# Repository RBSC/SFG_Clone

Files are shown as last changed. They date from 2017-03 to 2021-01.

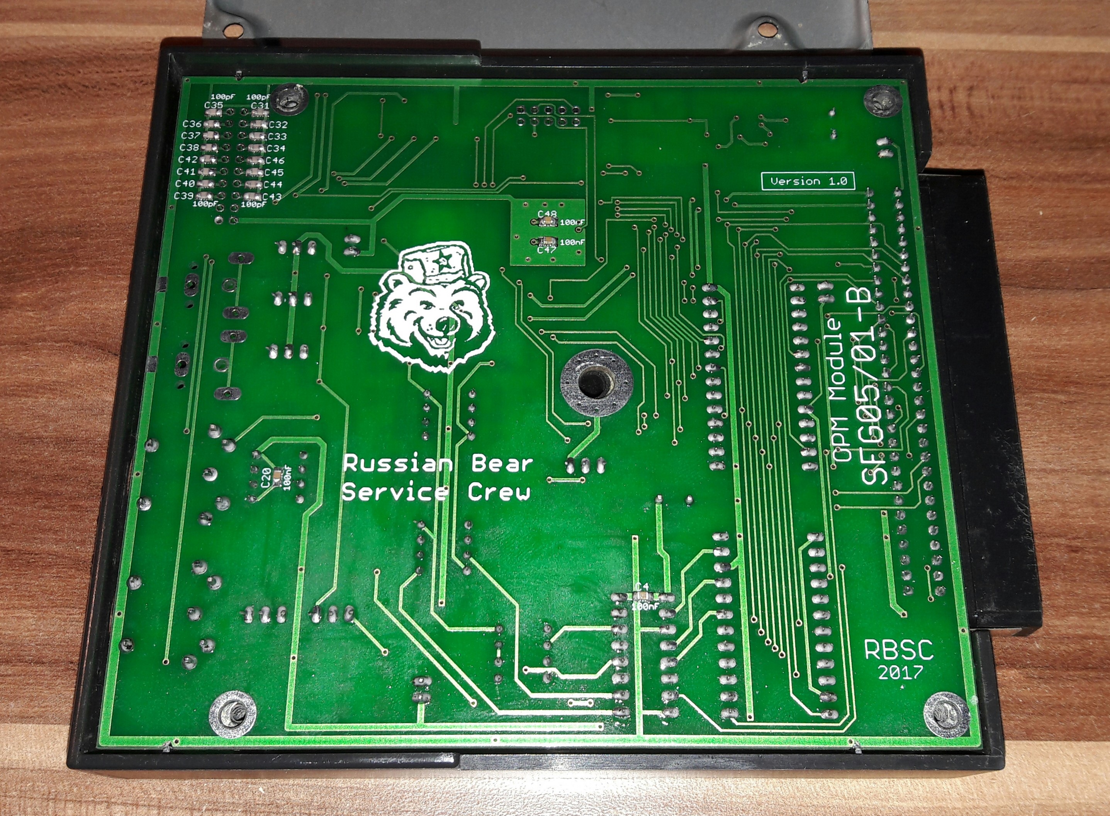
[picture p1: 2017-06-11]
Pics/assembled_clone_back.jpg

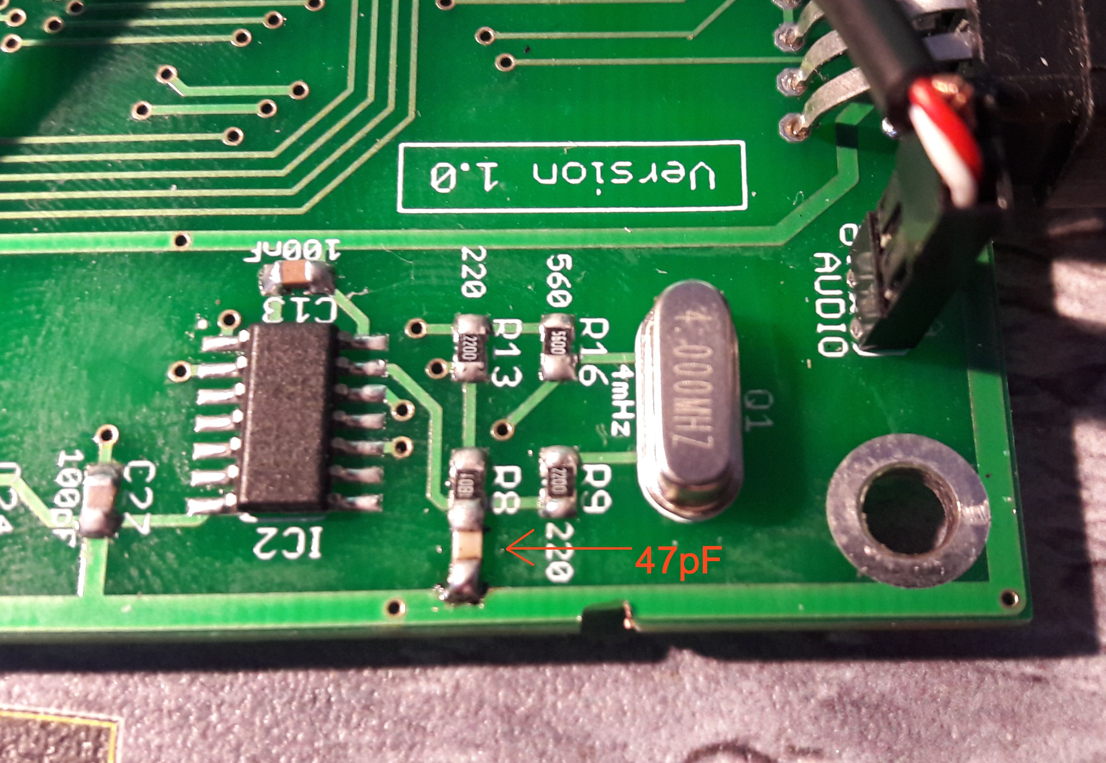
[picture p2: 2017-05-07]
Pics/74HCT04_fix.jpg

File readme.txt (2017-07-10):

Yamaha SFG 05/01-B Clone Board v1.1
Copyright (c) 2017 RBSC

The Setup
---------

After assembling, the board needs to be programmed in order to function properly. The following steps are necessary:

 1. Upload the Altera's firmware
 2. Program the BIOS with the provided ROM file

How to upload the firmware
--------------------------

The below instructions are for programming the Altera chip.

 1. Solder jumper pins to the "+5v" and "GND" soldering points on the board
 2. Prepare the ByteBlaster 2 programmer, open the Quartus II software, keep default JTAG selection
 3. Supply 5v power to the board via jumper pins (mind the correct polarity!)
 4. Connect the ByteBlaster's cable to the AS socket of the board (make sure you connect the cable correctly!)
 5. Click "Autodetect" in Quartus II software, the Altera chip should be found and ready for programming
 6. Use "Change file" option and select the .POF file from the "Firmware" directory
 7. Enable the checkboxes: "Program/Configure", "Verify" and "Blank Check"
 8. Click "Start" and monitor the programming and verification process

If the programming completed successfully, disconnect the ByteBlaster's cable and 5v power from the board.

You must also write the provided ROM file from BIOS directory into the 27C512 EPROM/EEPROM chip (DIP28) using any EEPROM
programmer. The ROM file contains 2 different BIOS versions that can be selected by the special jumper on the board. It is
also possible to use 27C256 EPROM/EEPROM chip to only have one of the BIOS versions instead of two.

Installing the audio wire
-------------------------

In order to connect the audio from the SFG board to MSX's internal amplifier a shielded wire must be installed between soldering
points named "X8A" and "X8B". The easiest way is to solder two 2-pin jumper pins onto those soldering points and attach a shielded
wire with Dupont connectors on both ends. The 74HCT04_fix.jpg shows such connection on the right side of the image. In order to
keep the connectors within the SFG casing, it's recommended to remove the plastic from the 2-pin jumper connectors and to cut the
pins a bit to allow the Dupont conenctor to settle down as close to the board as possible.

Alternatively a shielded wire can be soldered directly to the "X8A" and "X8B" soldering points. It is strongly recommended to use
a shielded wire for the above described connection to avoid interference from the digital components on the board. When installing
the wire please make sure that the shield is connected to the "GND" pin and the audio wire is connected to the other pin. Incorrect
connection may damage the board!

Installing into a case
----------------------

The SFG module can be installed into a network module case that was available in YIS503II, YIS503III and YIS805/128 MSX computers
that were available in Russia (USSR) in the 90-s. The holes for the MIDI connectors fit perfectly. However to be able to use
the RCA and external music keyboard, the front part of the case needs to be modified. See the sfg_case.jpg file for an example
of such installation.

Starting SFG BIOS
-----------------

To start the built-in SFG BIOS make sure that Basic is loaded and type "_musica" or "call musica" without quotes and press Enter.
The BIOS should start immediately. Depending on whether the jumper is installed or not, either the SFG-01 BIOS or SFG-05 BIOS will
be launched. To exit from BIOS software just reboot your MSX.

Notes
-----

If you are using 74HCT04 chip instead of 74LS04 please make sure you add one additional 47pf capacitor. See the 74HCT04_fix.jpg
image for capacitor mounting instructions. This picture shows how to install the capacitor on board version 1.0. Later boards
have the special placeholder for the capacitor.

IMPORTANT!
----------

The RBSC provides all the files and information for free, without any liability (see the disclaimer.txt file). The provided information,
software or hardware must not be used for commercial purposes unless permitted by the RBSC. Producing a small amount of bare boards for
personal projects and selling the rest of the batch is allowed without the permission of RBSC.

When the sources of the tools are used to create alternative projects, please always mention the original source and the copyright!

Contact information
-------------------

The members of RBSC group Wierzbowsky, Ptero and DJS3000 can be contacted via the MSX.ORG or ZX-PK.RU forums. Just send a personal
message and state your business.

The RBSC repository can be found here:

https://github.com/rbsc

-= ! MSX FOREVER ! =-

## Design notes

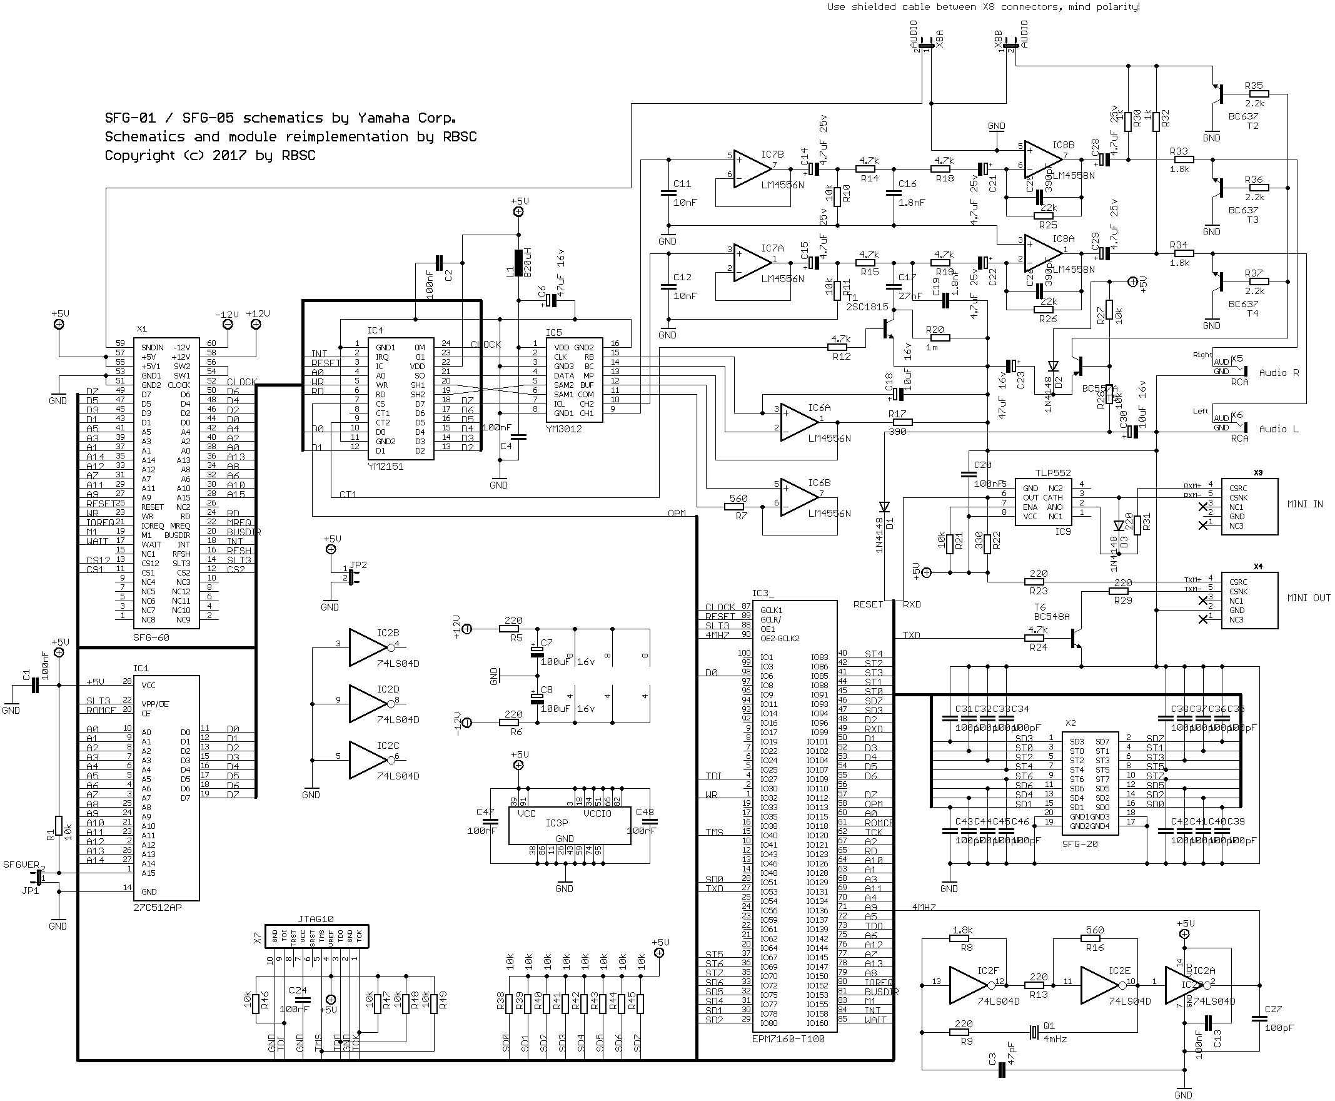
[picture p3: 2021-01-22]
Doc/schematics.png

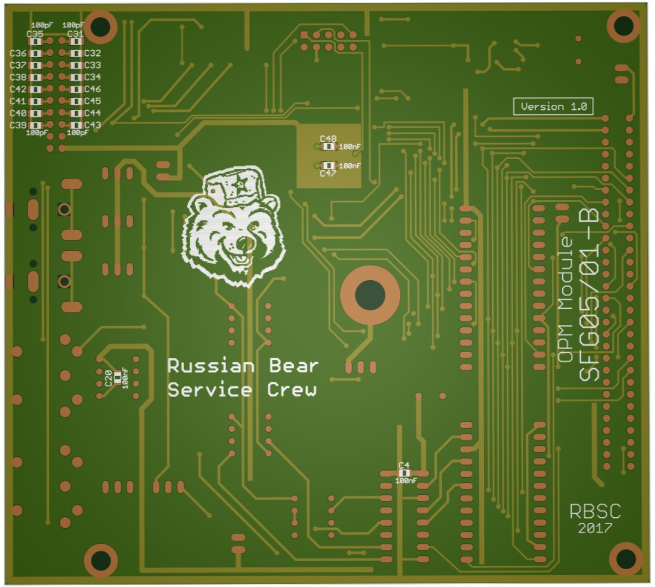
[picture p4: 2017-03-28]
Pics/board_back.jpg

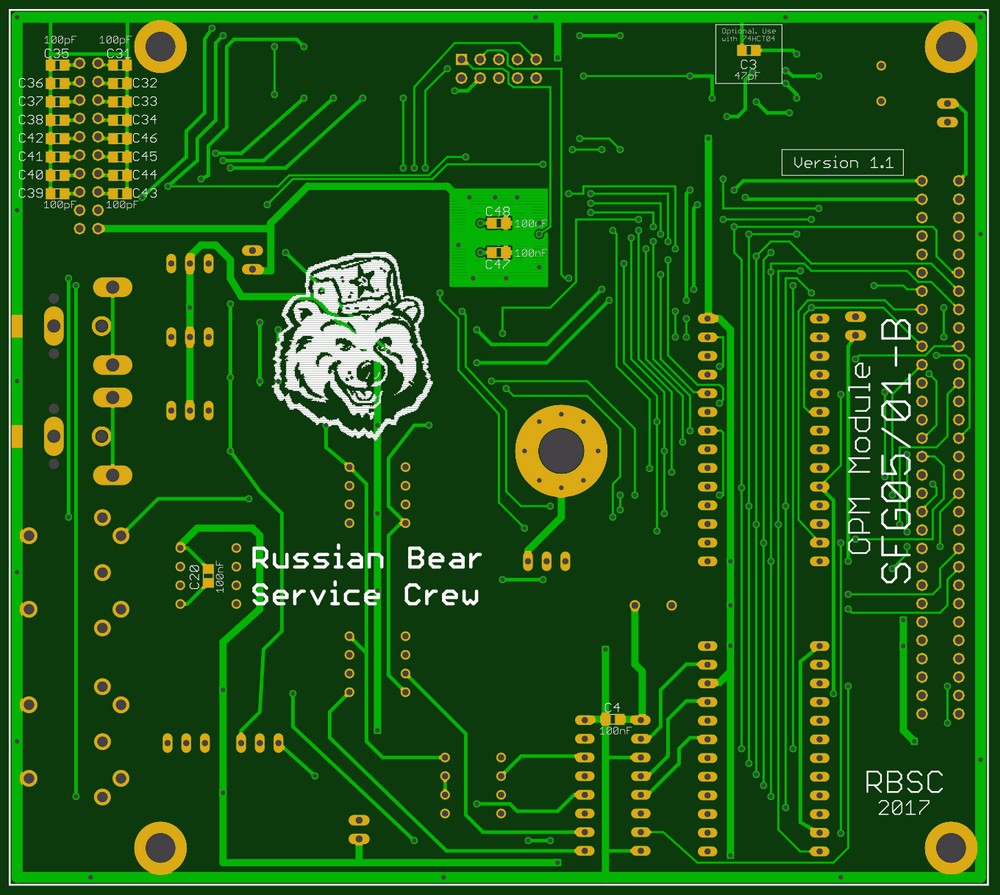
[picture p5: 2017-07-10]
Pics/board_v11_back.jpg

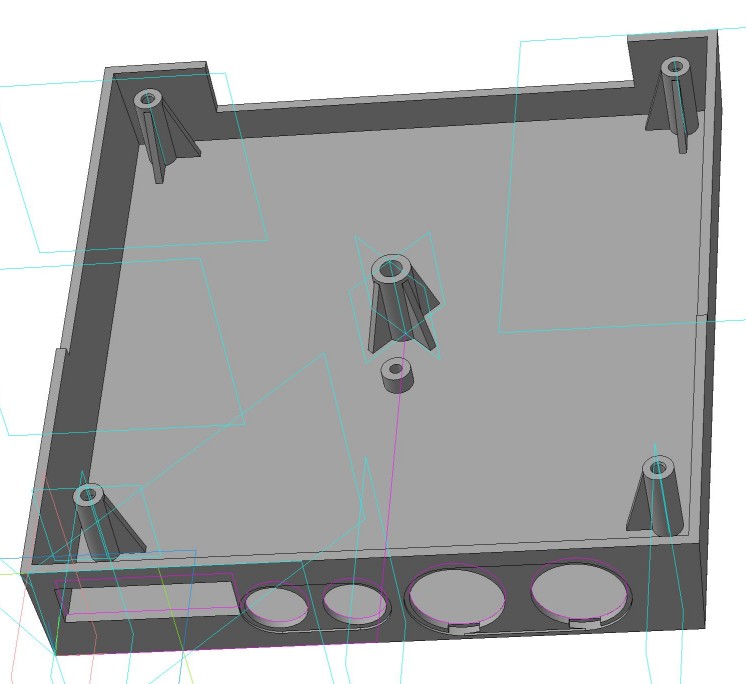
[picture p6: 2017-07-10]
Pics/sfg_case_model.jpg

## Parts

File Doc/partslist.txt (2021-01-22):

SFG 05/01-B Clone Version 1.1
Copyright (C) 2017 RBSC
Copyright (C) Yamaha Corporation
--------------------------------

Assembly variant: 

Part     Value                    Device                   Package              Library             Sheet

C1       100nF                    C-EUC0805                C0805                rcl                 1
C2       100nF                    C-EUC0805                C0805                rcl                 1
C3       47pF                     C-EUC0805                C0805                rcl                 1
C4       100nF                    C-EUC0805                C0805                rcl                 1
C6       47uF 16v                 CPOL-EUSMCC              SMC_C                rcl                 1
C7       100uF 16v                CPOL-EUSMCD              SMC_D                rcl                 1
C8       100uF 16v                CPOL-EUSMCD              SMC_D                rcl                 1
C11      10nF                     C-EUC0805                C0805                rcl                 1
C12      10nF                     C-EUC0805                C0805                rcl                 1
C13      100nF                    C-EUC0805                C0805                rcl                 1
C14      4.7uF 25v                CPOL-EUSMCB              SMC_B                rcl                 1
C15      4.7uF 25v                CPOL-EUSMCB              SMC_B                rcl                 1
C16      1.8nF                    C-EUC0805                C0805                rcl                 1
C17      27nF                     C-EUC0805                C0805                rcl                 1
C18      10uF 16v                 CPOL-EUSMCB              SMC_B                rcl                 1
C19      1.8nF                    C-EUC0805                C0805                rcl                 1
C20      100nF                    C-EUC0805                C0805                rcl                 1
C21      4.7uF 25v                CPOL-EUSMCB              SMC_B                rcl                 1
C22      4.7uF 25v                CPOL-EUSMCB              SMC_B                rcl                 1
C23      47uF 16v                 CPOL-EUSMCC              SMC_C                rcl                 1
C24      100nF                    C-EUC0805                C0805                rcl                 1
C25      390pF                    C-EUC0805                C0805                rcl                 1
C26      390pF                    C-EUC0805                C0805                rcl                 1
C27      100pF                    C-EUC0805                C0805                rcl                 1
C28      4.7uF 25v                CPOL-EUSMCB              SMC_B                rcl                 1
C29      4.7uF 25v                CPOL-EUSMCB              SMC_B                rcl                 1
C30      10uF 16v                 CPOL-EUSMCB              SMC_B                rcl                 1
C31      100pF                    C-EUC0805                C0805                rcl                 1
C32      100pF                    C-EUC0805                C0805                rcl                 1
C33      100pF                    C-EUC0805                C0805                rcl                 1
C34      100pF                    C-EUC0805                C0805                rcl                 1
C35      100pF                    C-EUC0805                C0805                rcl                 1
C36      100pF                    C-EUC0805                C0805                rcl                 1
C37      100pF                    C-EUC0805                C0805                rcl                 1
C38      100pF                    C-EUC0805                C0805                rcl                 1
C39      100pF                    C-EUC0805                C0805                rcl                 1
C40      100pF                    C-EUC0805                C0805                rcl                 1
C41      100pF                    C-EUC0805                C0805                rcl                 1
C42      100pF                    C-EUC0805                C0805                rcl                 1
C43      100pF                    C-EUC0805                C0805                rcl                 1
C44      100pF                    C-EUC0805                C0805                rcl                 1
C45      100pF                    C-EUC0805                C0805                rcl                 1
C46      100pF                    C-EUC0805                C0805                rcl                 1
C47      100nF                    C-EUC0805                C0805                rcl                 1
C48      100nF                    C-EUC0805                C0805                rcl                 1
D1       1N4148                   DIODE-MINIMELF           MINIMELF             diode               1
D2       1N4148                   DIODE-MINIMELF           MINIMELF             diode               1
D3       1N4148                   DIODE-MINIMELF           MINIMELF             diode               1
IC1      27C512AP                 27C512AP                 DIL28-6              microchip           1
IC2      74LS04D                  74LS04D                  SO14                 74xx-eu             1
IC3      EPM7160-T100             EPM7160-T100             TQFP100              altera              1
IC4      YM2151                   YM2151                   DIL24                ym2151              1
IC5      YM3012                   YM3012                   DIL16                ym3012              1
IC6      LM4556N                  LM4556N                  DIL08                LM4556              1
IC7      LM4556N                  LM4556N                  DIL08                LM4556              1
IC8      LM4558N                  LM4558N                  DIL08                LM4558              1
IC9      TLP552                   TLP552                   DIL08                TLP552              1
JP1      SFGVER                   JP1E                     JP1                  jumper              1
JP2                               JP1E                     JP1                  jumper              1
L1       820uH                    L-EU6000-XXX-RC          6000-XXXX-RC         rcl                 1
Q1       4mHz                     CRYSTALHC49S             HC49/S               crystal             1
R1       10k                      R-EU_R0805               R0805                resistor            1
R5       220                      R-EU_R0805               R0805                resistor            1
R6       220                      R-EU_R0805               R0805                resistor            1
R7       560                      R-EU_R0805               R0805                resistor            1
R8       1.8k                     R-EU_R0805               R0805                resistor            1
R9       220                      R-EU_R0805               R0805                resistor            1
R10      10k                      R-EU_R0805               R0805                resistor            1
R11      10k                      R-EU_R0805               R0805                resistor            1
R12      4.7k                     R-EU_R0805               R0805                resistor            1
R13      220                      R-EU_R0805               R0805                resistor            1
R14      4.7k                     R-EU_R0805               R0805                resistor            1
R15      4.7k                     R-EU_R0805               R0805                resistor            1
R16      560                      R-EU_R0805               R0805                resistor            1
R17      390                      R-EU_R0805               R0805                resistor            1
R18      4.7k                     R-EU_R0805               R0805                resistor            1
R19      4.7k                     R-EU_R0805               R0805                resistor            1
R20      1m                       R-EU_R0805               R0805                resistor            1
R21      10k                      R-EU_R0805               R0805                resistor            1
R22      330                      R-EU_R0805               R0805                resistor            1
R23      220                      R-EU_R0805               R0805                resistor            1
R24      4.7k                     R-EU_R0805               R0805                resistor            1
R25      22k                      R-EU_R0805               R0805                resistor            1
R26      22k                      R-EU_R0805               R0805                resistor            1
R27      10k                      R-EU_R0805               R0805                resistor            1
R28      10k                      R-EU_R0805               R0805                resistor            1
R29      220                      R-EU_R0805               R0805                resistor            1
R30      1k                       R-EU_R0805               R0805                resistor            1
R31      220                      R-EU_R0805               R0805                resistor            1
R32      1k                       R-EU_R0805               R0805                resistor            1
R33      1.8k                     R-EU_R0805               R0805                resistor            1
R34      1.8k                     R-EU_R0805               R0805                resistor            1
R35      2.2k                     R-EU_R0805               R0805                resistor            1
R36      2.2k                     R-EU_R0805               R0805                resistor            1
R37      2.2k                     R-EU_R0805               R0805                resistor            1
R38      10k                      R-EU_R0805               R0805                resistor            1
R39      10k                      R-EU_R0805               R0805                resistor            1
R40      10k                      R-EU_R0805               R0805                resistor            1
R41      10k                      R-EU_R0805               R0805                resistor            1
R42      10k                      R-EU_R0805               R0805                resistor            1
R43      10k                      R-EU_R0805               R0805                resistor            1
R44      10k                      R-EU_R0805               R0805                resistor            1
R45      10k                      R-EU_R0805               R0805                resistor            1
R46      10k                      R-EU_R0805               R0805                resistor            1
R47      10k                      R-EU_R0805               R0805                resistor            1
R48      10k                      R-EU_R0805               R0805                resistor            1
R49      10k                      R-EU_R0805               R0805                resistor            1
T1       2SC1815                  2SC1815                  TO92-ECB             transistor          1
T2       BC637                    BC637-NPN-TO92-ECB       TO92-ECB             transistor          1
T3       BC637                    BC637-NPN-TO92-ECB       TO92-ECB             transistor          1
T4       BC637                    BC637-NPN-TO92-ECB       TO92-ECB             transistor          1
T5       BC557A                   BC557A                   TO92-EBC             transistor-pnp      1
T6       BC548A                   BC548A                   TO92-EBC             transistor-npn      1
X1       SFG-60                   SFG-60                   SFG-60               sfg-60              1
X2       SFG-20                   SFG-20                   SFG-20               sfg-20              1
X3       MIDI_CONN_FEMALE_SUPPORT MIDI_CONN_FEMALE_SUPPORT DIN_5_FEMALE_SUPPORT SparkFun-Connectors 1
X4       MIDI_CONN_FEMALE_SUPPORT MIDI_CONN_FEMALE_SUPPORT DIN_5_FEMALE_SUPPORT SparkFun-Connectors 1
X5       RCA                      RCA                      RCA                  rca                 1
X6       RCA                      RCA                      RCA                  rca                 1
X7       JTAG10                   JTAG10                   JTAG10               jtag                1
X8A      AUDIO                    JP1E                     JP1                  jumper              1
X8B      AUDIO                    JP1E                     JP1                  jumper              1

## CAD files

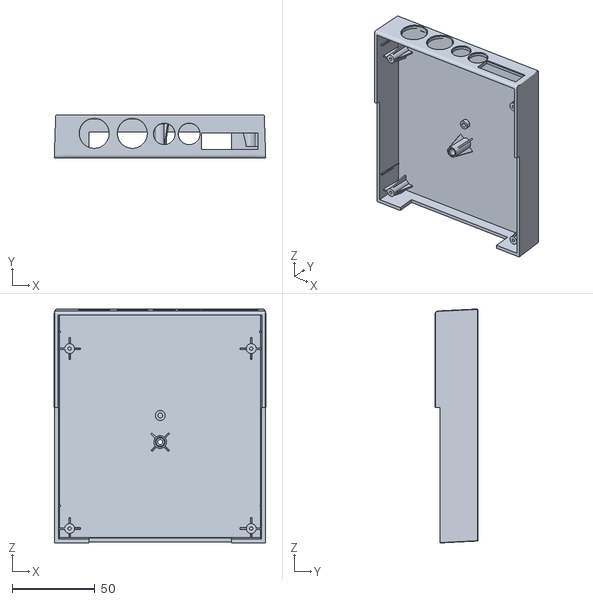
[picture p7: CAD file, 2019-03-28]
Case/SideSlotSFGModuleCase.stl
127.6 x 26.0 x 141.1

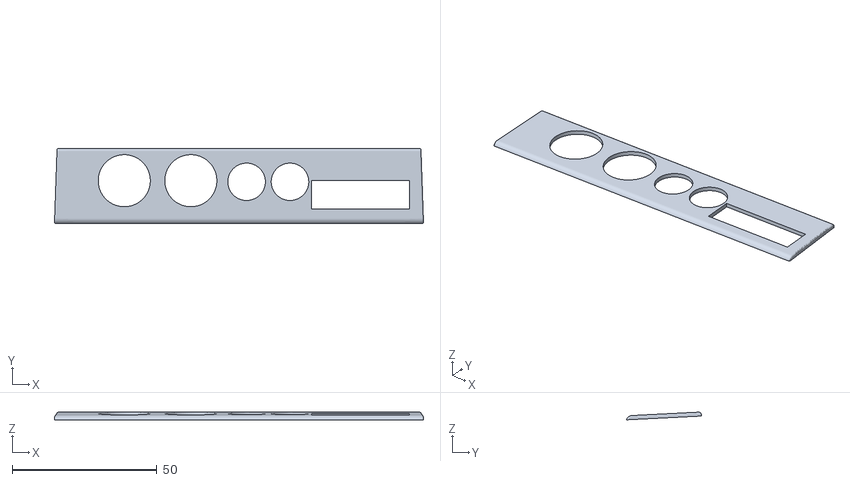
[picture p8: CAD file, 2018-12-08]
Case/FrontPanelThin.stl
127.6 x 25.9 x 2.66

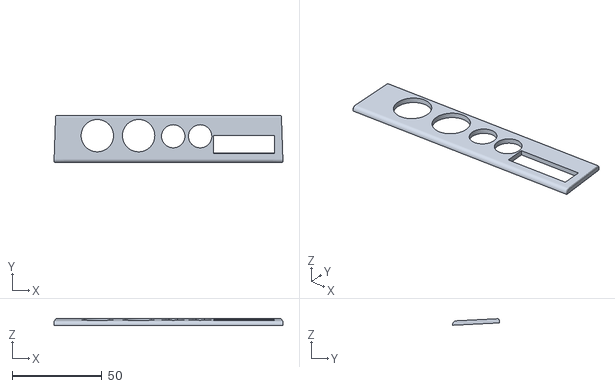
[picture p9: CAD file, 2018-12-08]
Case/FrontPanel.stl
127.6 x 26.0 x 3.66

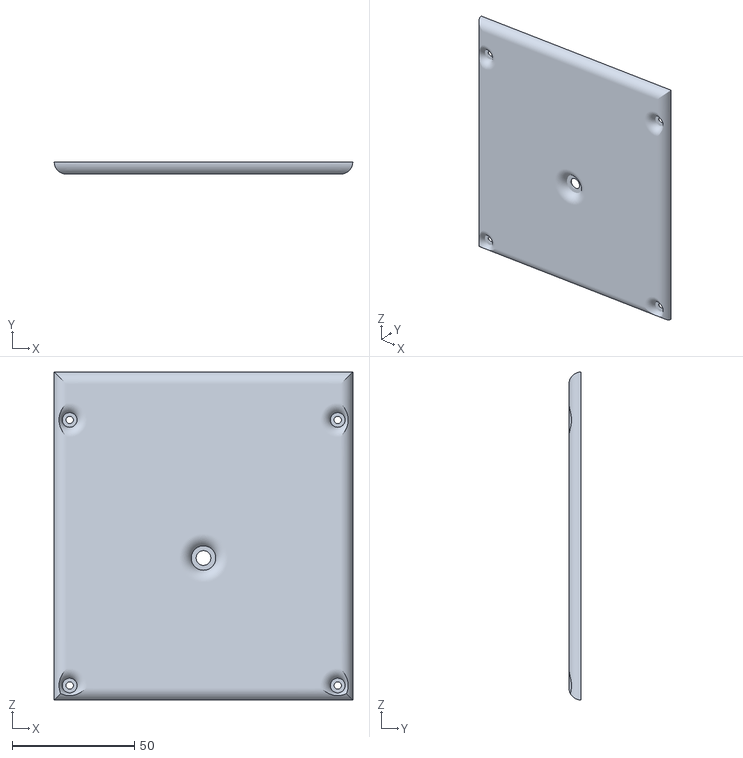
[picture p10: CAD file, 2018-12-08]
Case/SideSlotSFGModuleCover.stl
122.0 x 5.00 x 134.0

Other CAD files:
Case/SideSlotSFGModuleCase.f3d

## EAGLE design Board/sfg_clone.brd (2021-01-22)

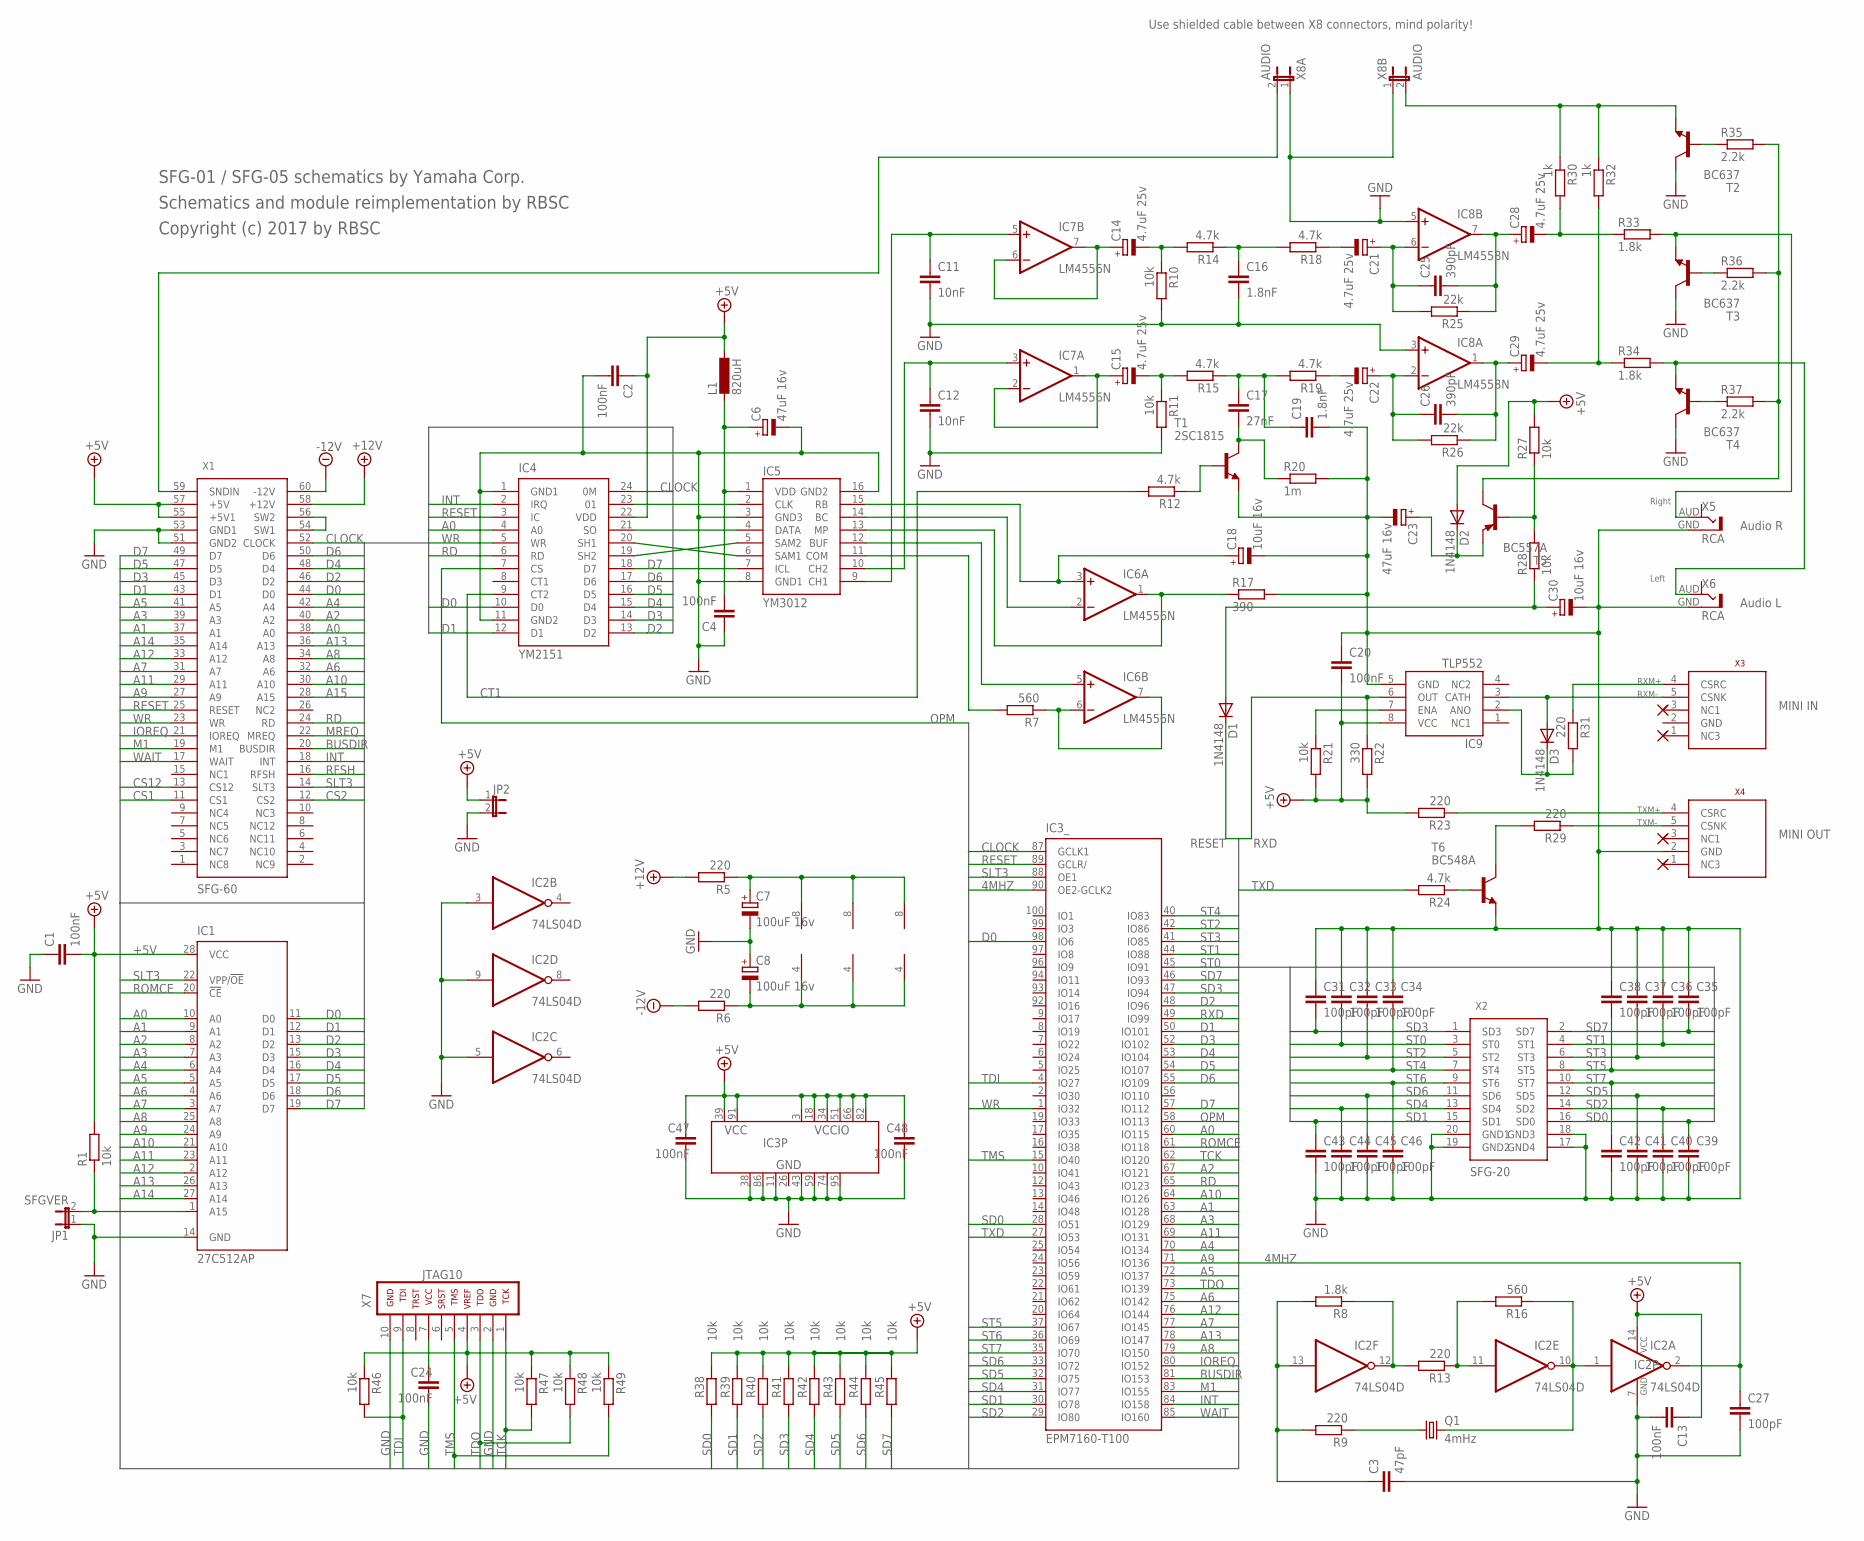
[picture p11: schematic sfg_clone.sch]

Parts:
C1, C2, C4, C13, C20, C24, C47, C48: 100nF; C0805
C3: 47pF; C0805
C6, C23: 47uF 16v; SMC_C
C7, C8: 100uF 16v; SMC_D
C11, C12: 10nF; C0805
C14, C15, C21, C22, C28, C29: 4.7uF 25v; SMC_B
C16, C19: 1.8nF; C0805
C17: 27nF; C0805
C18, C30: 10uF 16v; SMC_B
C25, C26: 390pF; C0805
C27, C31, C32, C33, C34, C35, C36, C37, C38, C39, C40, C41, C42, C43, C44, C45, C46: 100pF; C0805
D1, D2, D3: 1N4148; MINIMELF
IC1: 27C512AP; DIL28-6
IC2: 74LS04D; SO14
IC3: EPM7160-T100; TQFP100
IC4: YM2151; DIL24
IC5: YM3012; DIL16
IC6, IC7: LM4556N; DIL08
IC8: LM4558N; DIL08
IC9: TLP552; DIL08
JP1: SFGVER; JP1
JP2: JP1E; JP1
L1: 820uH; 6000-XXXX-RC
Q1: 4mHz; HC49/S
R1, R10, R11, R21, R27, R28, R38, R39, R40, R41, R42, R43, R44, R45, R46, R47, R48, R49: 10k; R0805
R5, R6, R9, R13, R23, R29, R31: 220; R0805
R7, R16: 560; R0805
R8, R33, R34: 1.8k; R0805
R12, R14, R15, R18, R19, R24: 4.7k; R0805
R17: 390; R0805
R20: 1m; R0805
R22: 330; R0805
R25, R26: 22k; R0805
R30, R32: 1k; R0805
R35, R36, R37: 2.2k; R0805
T1: 2SC1815; TO92-ECB
T2, T3, T4: BC637; TO92-ECB
T5: BC557A; TO92-EBC
T6: BC548A; TO92-EBC
X1: SFG-60
X2: SFG-20
X3, X4: MIDI_CONN_FEMALE_SUPPORT; DIN_5_FEMALE_SUPPORT
X5, X6: RCA
X7: JTAG10
X8A, X8B: AUDIO; JP1

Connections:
4MHZ: C27.1, IC2.2 (O), IC3.90 (OE2-GCLK2)
+5V: C1.2, C2.1, C13.1, C20.2, C47.1, C48.1, D2.A, IC1.28 (VCC), IC2.14 (VCC), IC3.3 (VCCIO), IC3.18 (VCCIO), IC3.34 (VCCIO), IC3.39 (VCC), IC3.51 (VCCIO), IC3.66 (VCCIO), IC3.82 (VCCIO), IC3.91 (VCC), IC4.22 (VDD), IC9.8 (VCC), JP2.1, L1.1, R1.2, R21.2, R22.2, R23.2, R27.2, R38.1, R39.1, R40.1, R41.1, R42.1, R43.1, R44.1, R45.1, R46.1, R47.1, R48.1, R49.1, X1.55 (+5V1), X1.57 (+5V), X7.4
+12V: R5.2, X1.58 (+12V)
+12V1: C7.+, IC6.8 (V+), IC7.8 (V+), IC8.8 (V+), R5.1
-12V: R6.2, X1.60 (-12V)
-12V1: C8.-, IC6.4 (V-), IC7.4 (V-), IC8.4 (V-), R6.1
A0: IC1.10 (A0), IC3.60 (IO115), IC4.4 (A0), X1.38 (A0)
A1: IC1.9 (A1), IC3.63 (IO128), X1.37 (A1)
A2: IC1.8 (A2), IC3.67 (IO121), X1.40 (A2)
A3: IC1.7 (A3), IC3.68 (IO129), X1.39 (A3)
A4: IC1.6 (A4), IC3.70 (IO134), X1.42 (A4)
A5: IC1.5 (A5), IC3.72 (IO137), X1.41 (A5)
A6: IC1.4 (A6), IC3.75 (IO142), X1.32 (A6)
A7: IC1.3 (A7), IC3.77 (IO145), X1.31 (A7)
A8: IC1.25 (A8), IC3.79 (IO150), X1.34 (A8)
A9: IC1.24 (A9), IC3.71 (IO136), X1.27 (A9)
A10: IC1.21 (A10), IC3.64 (IO126), X1.30 (A10)
A11: IC1.23 (A11), IC3.69 (IO131), X1.29 (A11)
A12: IC1.2 (A12), IC3.76 (IO144), X1.33 (A12)
A13: IC1.26 (A13), IC3.78 (IO147), X1.36 (A13)
A14: IC1.27 (A14), X1.35 (A14)
A15: X1.28 (A15)
BUSDIR: IC3.81 (IO153), X1.20 (BUSDIR)
CLOCK: IC3.87 (GCLK1), IC4.24 (0M), X1.52 (CLOCK)
CS1: X1.11 (CS1)
CS2: X1.12 (CS2)
CS12: X1.13 (CS12)
CT1: IC4.9 (CT2), R12.2
D0: IC1.11 (D0), IC3.98 (IO6), IC4.10 (D0), X1.44 (D0)
D1: IC1.12 (D1), IC3.50 (IO101), IC4.12 (D1), X1.43 (D1)
D2: IC1.13 (D2), IC3.48 (IO96), IC4.13 (D2), X1.46 (D2)
D3: IC1.15 (D3), IC3.52 (IO102), IC4.14 (D3), X1.45 (D3)
D4: IC1.16 (D4), IC3.53 (IO104), IC4.15 (D4), X1.48 (D4)
D5: IC1.17 (D5), IC3.54 (IO107), IC4.16 (D5), X1.47 (D5)
D6: IC1.18 (D6), IC3.55 (IO109), IC4.17 (D6), X1.50 (D6)
D7: IC1.19 (D7), IC3.57 (IO112), IC4.18 (D7), X1.49 (D7)
GND: C1.1, C2.2, C3.2, C4.1, C6.-, C7.-, C8.+, C11.2, C12.2, C13.2, C16.2, C18.-, C19.2, C20.1, C23.-, C24.2, C27.2, C30.-, C31.1, C32.1, C33.1, C34.1, C35.1, C36.1, C37.1, C38.1, C39.2, C40.2, C41.2, C42.2, C43.2, C44.2, C45.2, C46.2, C47.2, C48.2, IC1.14 (GND), IC2.3 (I), IC2.5 (I), IC2.7 (GND), IC2.9 (I), IC3.11 (GND), IC3.26 (GND), IC3.38 (GND), IC3.43 (GND), IC3.59 (GND), IC3.74 (GND), IC3.86 (GND), IC3.95 (GND), IC4.1 (GND1), IC4.11 (GND2), IC5.3 (GND3), IC5.8 (GND1), IC5.16 (GND2), IC8.3 (+IN), IC8.5 (+IN), IC9.5 (GND), JP1.1, JP2.2, R10.2, R11.2, R17.2, R20.2, T1.E, T2.C, T3.C, T4.C, T6.E, X1.51 (GND2), X1.53 (GND1), X2.17 (GND4), X2.18 (GND3), X2.19 (GND2), X2.20 (GND1), X4.2 (GND), X5.GND (GND1), X6.GND (GND1), X7.2, X7.10, X8A.1, X8B.1
INT: IC3.84 (IO158), IC4.2 (IRQ), X1.18 (INT)
IOREQ: IC3.80 (IO152), X1.21 (IOREQ)
M1: IC3.83 (IO155), X1.19 (M1)
MREQ: X1.22 (MREQ)
unnamed: IC1.1 (A15), JP1.2, R1.1
unnamed: C24.1, X7.7
unnamed: X1.54 (SW1), X1.56 (SW2)
unnamed: R30.1, R32.1, T2.E, X8B.2
unnamed: X1.59 (SNDIN), X8A.2
unnamed: C3.1, IC2.13 (I), R8.2, R9.2
unnamed: IC2.12 (O), R8.1, R13.2
unnamed: IC2.1 (I), IC2.10 (O), Q1.2, R16.1
unnamed: Q1.1, R9.1
unnamed: IC2.11 (I), R13.1, R16.2
unnamed: R24.1, T6.B
unnamed: R29.2, T6.C
unnamed: R29.1, X4.5 (CSNK)
unnamed: R23.1, X4.4 (CSRC)
unnamed: D3.A, IC9.3 (CATH), X3.5 (CSNK)
unnamed: R31.1, X3.4 (CSRC)
unnamed: IC9.7 (ENA), R21.1
unnamed: D3.C, IC9.2 (ANO), R31.2
unnamed: IC4.23 (01), IC5.2 (CLK)
unnamed: IC4.21 (SO), IC5.4 (DATA)
unnamed: C28.-, R30.2, R33.1
unnamed: IC4.20 (SH1), IC5.6 (SAM1)
unnamed: C4.2, C6.+, IC5.1 (VDD), L1.2
unnamed: IC4.19 (SH2), IC5.5 (SAM2)
unnamed: IC6.6 (-IN), IC6.7 (OUT), R7.1
unnamed: IC5.11 (COM), R7.2
unnamed: C12.1, IC5.10 (CH2), IC7.3 (+IN)
unnamed: IC5.12 (BUF), IC6.5 (+IN)
unnamed: IC5.13 (MP), IC6.1 (OUT), R17.1
unnamed: C18.+, IC5.15 (RB), IC6.3 (+IN)
unnamed: C21.+, C25.1, IC8.6 (-IN), R25.2
unnamed: C14.+, IC7.6 (-IN), IC7.7 (OUT)
unnamed: C15.+, IC7.1 (OUT), IC7.2 (-IN)
unnamed: C11.1, IC5.9 (CH1), IC7.5 (+IN)
unnamed: C14.-, R10.1, R14.2
unnamed: C15.-, R11.1, R15.2
unnamed: IC5.14 (BC), IC6.2 (-IN)
unnamed: C17.2, R20.1, T1.C
unnamed: C16.1, R14.1, R18.2
unnamed: C17.1, C19.1, R15.1, R19.2
unnamed: C22.+, C26.1, IC8.2 (-IN), R26.2
unnamed: C22.-, R19.1
unnamed: C21.-, R18.1
unnamed: R12.1, T1.B
unnamed: C26.2, C29.+, IC8.1 (OUT), R26.1
unnamed: C25.2, C28.+, IC8.7 (OUT), R25.1
unnamed: C29.-, R32.2, R34.1
unnamed: R33.2, T3.E, X5.AUD
unnamed: R34.2, T4.E, X6.AUD
unnamed: R35.1, T2.B
unnamed: R35.2, R36.2, R37.2, T5.C
unnamed: R36.1, T3.B
unnamed: R37.1, T4.B
unnamed: C30.+, D1.A, R28.1
unnamed: C23.+, D2.C, T5.E
unnamed: R27.1, R28.2, T5.B
OPM: IC3.58 (IO113), IC4.7 (CS)
RD: IC3.65 (IO123), IC4.6 (RD), X1.24 (RD)
RESET: D1.C, IC3.89 (GCLR/), IC4.3 (IC), IC5.7 (ICL), X1.25 (RESET)
RFSH: X1.16 (RFSH)
ROMCE: IC1.20 (!CE), IC3.61 (IO118)
RXD: IC3.49 (IO99), IC9.6 (OUT), R22.1
SD0: C39.1, IC3.28 (IO51), R38.2, X2.16 (SD0)
SD1: C43.1, IC3.30 (IO78), R39.2, X2.15 (SD1)
SD2: C40.1, IC3.29 (IO80), R40.2, X2.14 (SD2)
SD3: C31.2, IC3.47 (IO94), R41.2, X2.1 (SD3)
SD4: C44.1, IC3.31 (IO77), R42.2, X2.13 (SD4)
SD5: C41.1, IC3.32 (IO75), R43.2, X2.12 (SD5)
SD6: C45.1, IC3.33 (IO72), R44.2, X2.11 (SD6)
SD7: C35.2, IC3.46 (IO93), R45.2, X2.2 (SD7)
SLT3: IC1.22 (VPP/!OE), IC3.88 (OE1), X1.14 (SLT3)
ST0: C32.2, IC3.45 (IO91), X2.3 (ST0)
ST1: C36.2, IC3.44 (IO88), X2.4 (ST1)
ST2: C33.2, IC3.42 (IO86), X2.5 (ST2)
ST3: C37.2, IC3.41 (IO85), X2.6 (ST3)
ST4: C34.2, IC3.40 (IO83), X2.7 (ST4)
ST5: C38.2, IC3.37 (IO67), X2.8 (ST5)
ST6: C46.1, IC3.36 (IO69), X2.9 (ST6)
ST7: C42.1, IC3.35 (IO70), X2.10 (ST7)
TCK: IC3.62 (IO120), R47.2, X7.1
TDI: IC3.4 (IO27), R46.2, X7.9
TDO: IC3.73 (IO139), R48.2, X7.3
TMS: IC3.15 (IO40), R49.2, X7.5
TXD: IC3.27 (IO53), R24.2
WAIT: IC3.85 (IO160), X1.17 (WAIT)
WR: IC3.1 (IO32), IC4.5 (WR), X1.23 (WR)

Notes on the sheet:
Use shielded cable between X8 connectors, mind polarity!
SFG-01 / SFG-05 schematics by Yamaha Corp.
Schematics and module reimplementation by RBSC
Copyright (c) 2017 by RBSC
Audio R
Audio L
MINI IN
MINI OUT
RXM+
RXM-
TXM-
TXM+
Right
Left

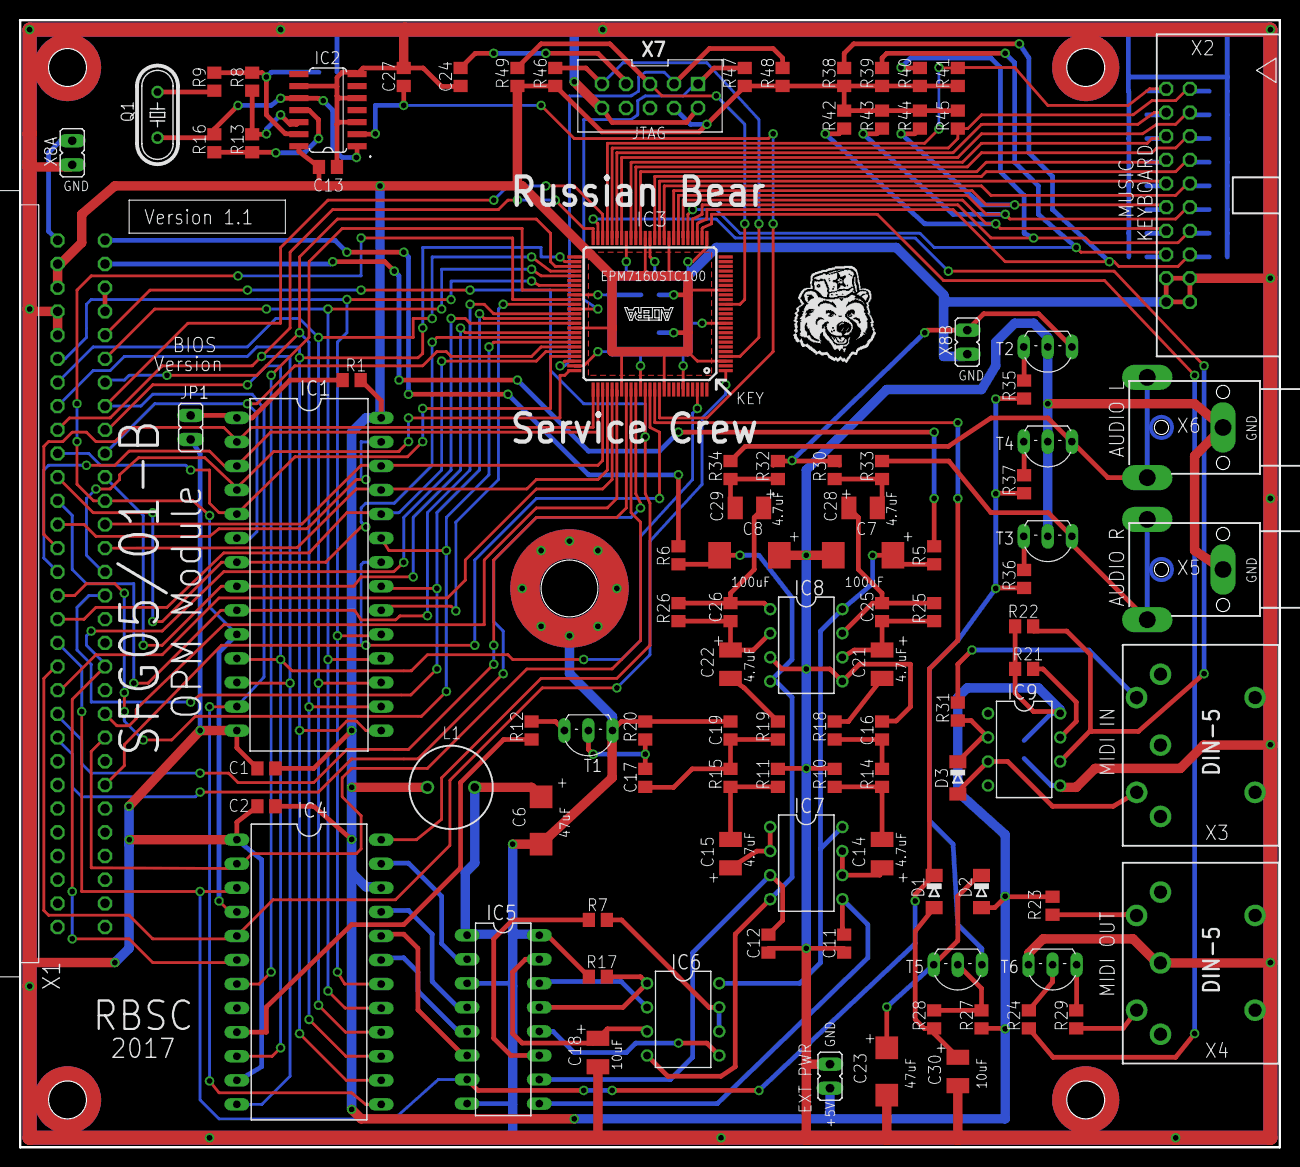
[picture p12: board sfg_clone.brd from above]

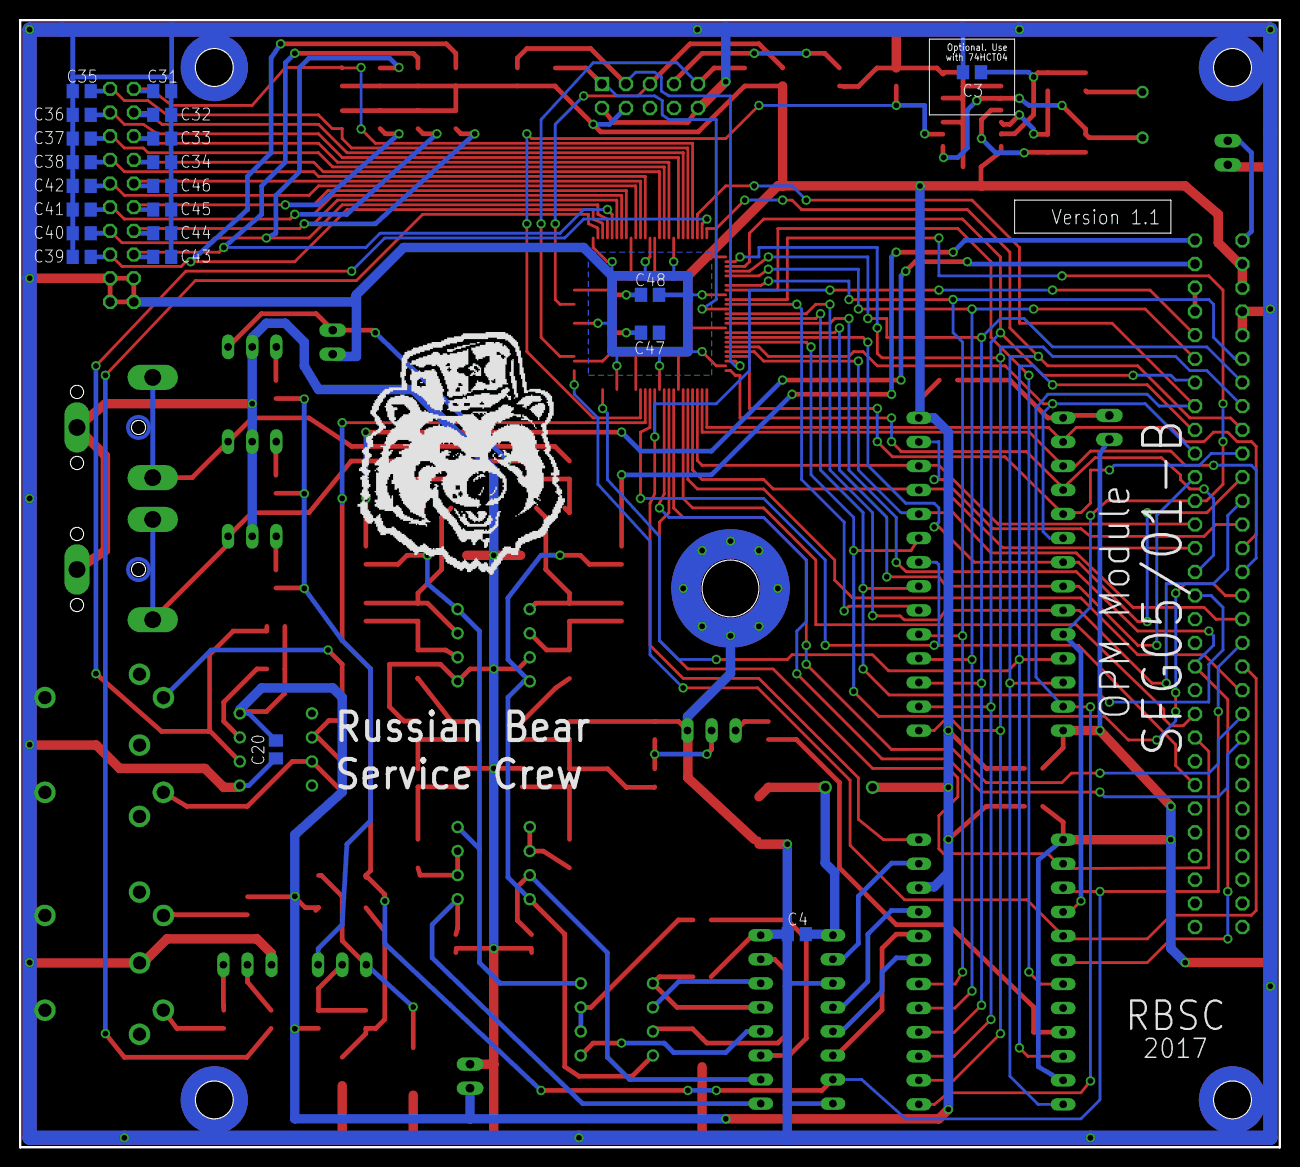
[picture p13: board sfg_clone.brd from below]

Board: 2 copper layers, 133.0 x 119.0 mm, 122 parts (21 on the bottom side), 121 nets.

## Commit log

2016-06-02 Board picture
2017-03-28 First major commit
    New board revision, schematics, Gerbers
    [sfg_clone.brd, sfg_clone.sch]
2017-05-07 The sources for v1.0 board
    [sfg_clone.brd, sfg_clone.sch]
2017-05-20 Added firmware files
    [sfg_clone.brd, sfg_clone.sch]
2017-07-10 Board updated to version 1.1
    Board updated to version 1.1
    [sfg_clone.brd, sfg_clone.sch]
2018-12-08 Release 08.12.2018
    SFG module case (RBSC version)
    [RBSC_SFG_Module.f3d, SideSlotSFGModuleCase.stl, SideSlotSFGModuleCover.stl]
2018-12-08 Release 08.12.2018
    Added front panel model to be used with the network module case
    [FrontPanel.stl, FrontPanelThin.stl, RBSC SFG Module Case.f3d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]
2019-03-28 Updated 28.03.2019
    Reduced screw holes by 1mm.
    [RBSC SFG Module Case.f3d, SFG Front Panel Thin.f3d, SFG Front Panel.f3d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]
2019-05-01 Updated 01.05.2019
    3D model of the case added, use Fusion 360
    [SideSlotSFGModuleCase.f3d]
2021-01-22 Updated 21.01.2021
    Fixed schematics and partslist (the value of the coil was incorrectly
    specified)
    [sfg_clone.brd, sfg_clone.sch]

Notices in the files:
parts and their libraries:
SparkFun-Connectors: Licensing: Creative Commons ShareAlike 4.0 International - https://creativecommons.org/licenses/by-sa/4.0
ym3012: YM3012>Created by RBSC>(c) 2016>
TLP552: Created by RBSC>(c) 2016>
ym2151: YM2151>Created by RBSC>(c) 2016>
